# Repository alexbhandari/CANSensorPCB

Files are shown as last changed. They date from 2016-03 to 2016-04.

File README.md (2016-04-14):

# Sensor to CAN Bus Remote IO PCB
Many wires in, two wires out. 24 input channels on the board interface with analog and digital sensors. Performs analog to digital to CAN protocol conversion.

## Changelog
| Release | Changes |
| --- | --- |
|  | Pre-release |

## PCB Design

- Microcontroller: RM42L432BPZT
- Input Stage: Filtering, Voltage scaling, Circuit Protection
- Output Stage: 2 Isolated CAN transceivers
- Power: 5V board power, LDO supply creates 3.3V and 1.2V

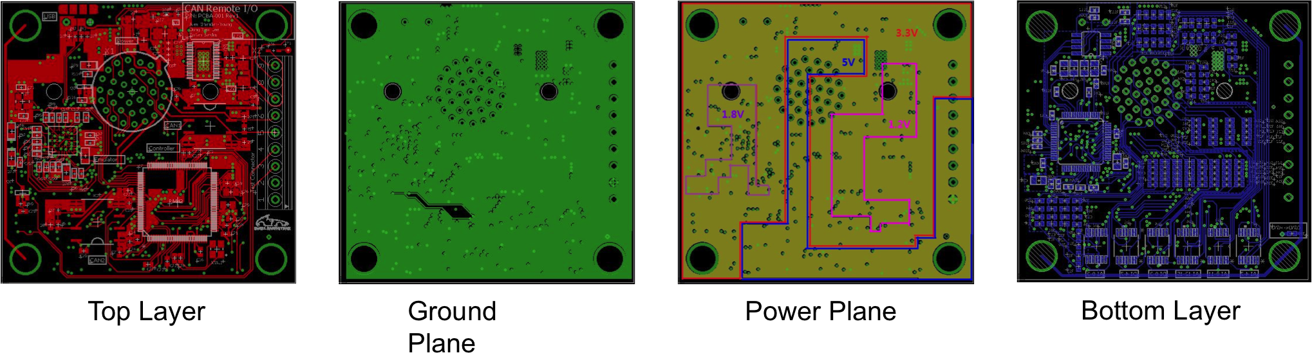
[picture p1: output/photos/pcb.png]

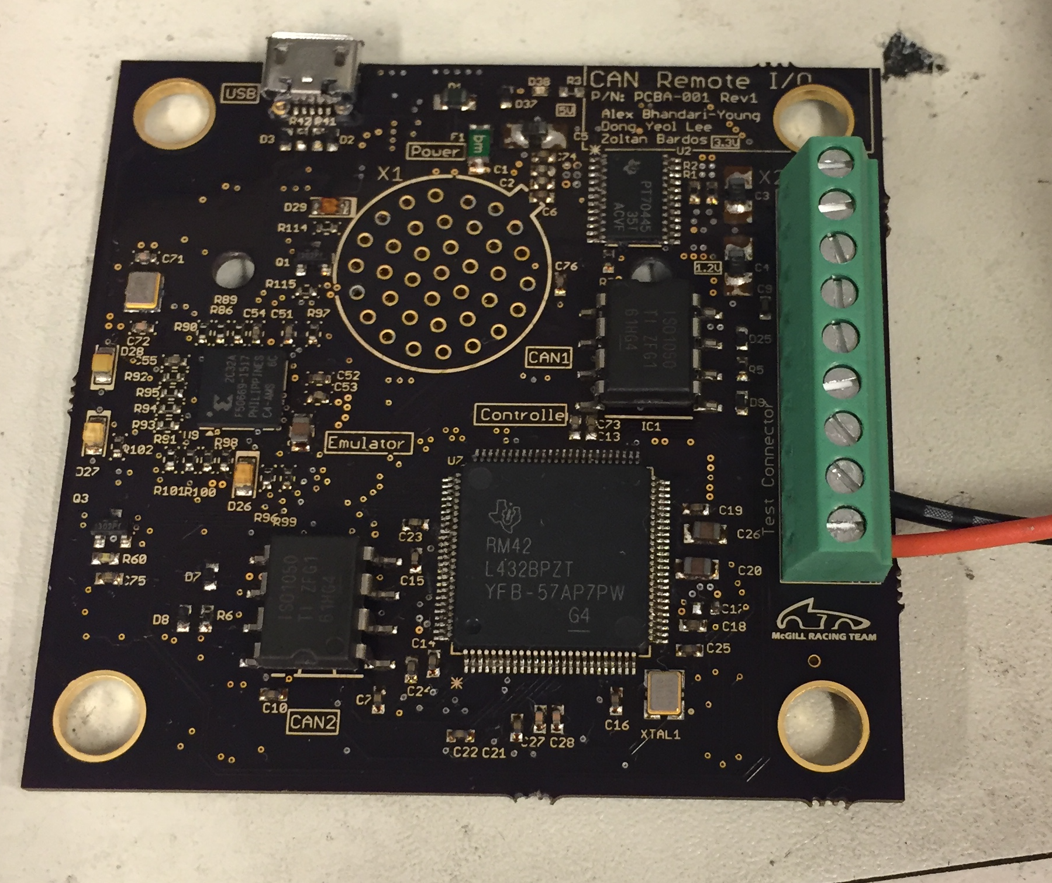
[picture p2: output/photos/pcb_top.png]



## [Code Repo](https://github.com/alexbhandari/RM42-CAN-Sensor-Code)

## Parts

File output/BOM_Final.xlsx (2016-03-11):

Item # | Ref Des | Qty | Manufacturer | Mfg Part # | Description | Package | Type | Your Instructions | Value | Device
 | C8, C32, C33, C34, C35, C43, C44, C45 | 8 | Murata Electronics North America | GRM155R71H103KA88D | CAP CER 10000PF 50V X7R 0402 | 0402 | SMD |  | .01uF | CAP0402
 | C7, C9, C10, C76 | 4 | Murata Electronics North America | GRM155R71C104JA88D | CAP CER 0.1UF 16V X7R 0402 | 0402 | SMD |  | .1uF | CAP0402
 | R86, R89, R90, R91, R92, R93, R94, R95, R103, R104, R105 | 11 | Yageo | RC0402JR-070RL | RES SMD 0.0OHM JUMPER 1/16W 0402 | 0402 | SMD |  | 0R | RES0402
 | F1 | 1 | Bel Fuse Inc. | 0ZCJ0050AF2E | PTC RESTTBLE 0.50A 24V CHIP 1206 | 1206 | SMD |  | 0ZCJ0050AF2E | PTCFUSE-1206
 | R7, R115 | 2 | Yageo | RC0402FR-07100KL | RES SMD 100K OHM 1% 1/16W 0402 | 0402 | SMD |  | 100K | RES0402
 | C13, C14, C15, C16, C17, C18, C19, C21, C22, C23, C24, C25, C73, C75, C51, C52, C53, C54, C55, C60, C61, C62, C63, C64, C65, C66, C67, C68, C69, C70, C6, C74 | 32 | Murata Electronics North America | GRM155R71C104JA88D | CAP CER 0.1UF 16V X7R 0402 | 0402 | SMD |  | 100nF | CAP0402
 | R97, R102 | 2 | Yageo | RC0402JR-0710KL | RES SMD 10K OHM 5% 1/16W 0402 | 0402 | SMD |  | 10K | RES0402
 | R5,R6,R114 | 3 | Vishay Dale | CRCW0402120RJNEDHP | RES SMD 120 OHM 5% 1/5W 0402 | 0402 | SMD |  | 120R | RES0402
 | R110 | 1 | Yageo | RC0402JR-0712KL | RES SMD 12K OHM 5% 1/16W 0402 | 0402 | SMD |  | 12K | RES0402
 | Y1 | 1 | TXC | 7M-12.000MEEQ-T | Crystal 12MHZ | 3.2*2.5mm | SMD |  | 12M | CRYSTAL-SMD
 | X2 | 1 | Phoenix Contact | 1751316 | CONN TERM BLOCK 9POS 3.5MM | 32*7.3mm | Through Hole |  | 1751316 | 1751316
 | R40, R66, R67, R68, R69, R77, R78, R79, R98, R99, R100, R101 | 12 | Yageo | RC0402FR-071KL | RES SMD 1K OHM 1% 1/16W 0402 | 0402 | SMD |  | 1K | RES0402
 | C1, C2,C11, C12, C29, C30, C31, C36, C37, C38, C39, C40, C41, C42, C47, C48, C49, C50 | 18 | Murata Electronics North America | GRM155R60J105KE19D | CAP CER 1UF 6.3V X5R 0402 | 0402 | SMD |  | 1uF | CAP0402
 | R108 | 1 | Panasonic Electronic Components | ERJ-2GEJ222X | RES SMD 2.2K OHM 5% 1/10W 0402 | 0402 | SMD |  | 2.2K | RES0402
 | R8,R10, R12, R14, R16, R18, R20, R22, R24, R26, R28, R30, R32, R34, R36, R38, R43, R45, R47, R49, R51, R53, R55, R57 | 24 | Susumu | RR0510P-203-D | RES SMD 20K OHM 0.5% 1/16W 0402 | 0402 | SMD |  | 20K | RES0402
 | R96,R106, R107 | 3 | Panasonic Electronic Components | ERJ-2RKF2000X | RES SMD 200 OHM 1% 1/10W 0402 | 0402 | SMD |  | 200 | RES0402
 | R41, R42 | 2 | Yageo | RC0402FR-0722RL | RES SMD 22 OHM 1% 1/16W 0402 | 0402 | SMD |  | 22 | RES0402
 | FB1, FB2 | 2 | MURATA | BLM21PG221SN1D | Ferrite Bead | 0805 | SMD |  | 220R @ 100M | INDUCTOR
 | C27, C28, C71, C72 | 4 | Johanson Technology Inc. | 500R07S220JV4T | CAP CER 22PF 50V NP0 0402 | 0402 | SMD |  | 22pF | CAP0402
 | C3, C5 | 2 | AVX Corporation | F920J226MPA | CAP TANT 22UF 6.3V 20% 0805 | 0805 | SMD |  | 22uF | CAP0805
 | R3 | 1 | Samsung Electro-Mechanics America, Inc. | RC1005F6190CS | RES SMD 619 OHM 1% 1/16W 0402 | 0402 | SMD |  | 619 | RES0402
 | R1, R2 | 2 | Yageo | RC0402FR-07249KL | RES SMD 249K OHM 1% 1/16W 0402 | 0402 | SMD |  | 250k | RES0402
 | R9, R11, R13, R15, R17, R19, R21, R23, R25, R27, R29, R31, R33, R35, R37, R39, R44, R46, R48, R50, R52, R54, R56, R58, R60 | 25 | Susumu | RR0510P-393-D | RES SMD 39K OHM 0.5% 1/16W 0402 | 0402 | SMD |  | 39K | RES0402
 | R109, R111, R112, R113 | 4 | Yageo | RC0402JR-074K7L | RES SMD 4.7K OHM 5% 1/16W 0402 | 0402 | SMD |  | 4.7K | RES0402
 | C20, C26, C46, C56, C57, C58, C59 | 7 | Taiyo Yuden | LMK212BJ475KD-T | CAP CER 4.7UF 10V X5R 0805 | 0805 | SMD |  | 4.7uF | CAP0805
 | C4 | 1 | Murata Electronics North America | GRM155R71E473KA88D | CAP CER 0.047UF 25V X7R 0402 | 0402 | SMD |  | 47uF | CAP0402
 | R61, R62, R63, R64, R65, R70, R71, R72, R73, R74, R75, R76, R81, R82, R83, R84 | 16 | Panasonic Electronic Components | ERJ-2RKF6980X | RES SMD 698 OHM 1% 1/10W 0402 | 0402 | SMD |  | 698 | RES0402
 | XTAL1 | 1 | TXC | 7M-16.000MAAJ-T | Crystal 16MHZ | 3.2*2.5mm | SMD |  | 7M-16.000MAAJ-T | CRYSTAL-SMD
 | U11 | 1 | Microchip Technology | 93LC56C-I/SN | IC EEPROM 2KBIT 3MHZ 8SOIC | 8-SOIC | SMD |  | 93LC56C-I/SN | 93LC56C-I/SN
 | X1 | 1 | Deutch | AS214-35-PN | Autosport connector |  |  | do not populate | AS14-35 | AS14-35
 | R59 | 1 |  |  |  |  |  |  | DNP | RES0402
 | Q1, Q3 | 2 | Fairchild Semiconductor | FDV302P | MOSFET P-CH 25V 120MA SOT-23 | SOT-23 | SMD |  | FDV302P | PMOSSOT23
 | U10 | 1 | FTDI, Future Technology Devices International Ltd | FT2232HL | IC USB HS DUAL UART/FIFO 64-LQFP | 64-LQFP | SMD |  | FT2232HL | FT2232HL
 | IC1, IC2 | 2 | Texas Instruments | ISO1050DUBR | IC TXRX CAN 5V 8SOP | 8-SOP | SMD |  | ISO1050DUB | ISO1050DUB
 | U1, U3, U4, U5, U6, U8 | 6 | Texas Instruments | LM324PW | IC OPAMP GP 1.2MHZ 14TSSOP | 14-TSSOP | SMD |  | LM324PW | LM324PW
 | U7 | 1 | Texas Instruments | RM42L432BPZT | IC MCU 16BIT 384KB FLASH 100LQFP | 100-LQFP | SMD |  | RM42L432_PZ_100RM42L432_PZ_100 | RM42L432_PZ_100RM42L432_PZ_100
 | U2 | 1 | Texas Instruments | TPS70445PWP | IC REG LDO 3.3V/1.2V 24HTSSOP | 24-HTSSOP | SMD |  | TPS70445_PWP_24 | TPS70445_PWP_24
 | D2, D3, D4, D5, D6, D7, D8, D9, D10, D11, D12, D13, D14, D15, D16, D17, D18, D19, D20, D21, D22, D23, D24, D25, D30, D31, D32, D33, D34, D35 | 30 | Semtech Corporation | UCLAMP1201P.TCT | TVS DIODE 12VWM 25VC 2SLP | 0402 | SMD |  | TVS DIODE | TVS0402
 | U$5 | 1 | Molex, LLC | 1050170001 | USB - micro B Receptacle Connector 5 Position Board Cutout, Surface Mount, Right Angle | 7.5*5.0mm | SMD |  | USB-CON-5PIN-105017-0001 | USB-CON-5PIN-105017-0001
 | U9 | 1 | Xilinx Inc. | XC2C32A-6CP56C | IC CPLD 32MC 5.5NS 56BGA | 56-LFBGA, CSPBGA | SMD |  | XC2C32A-6CP56C | XC2C32A-6CP56C | possibe replacment: XC2C64A-7CPG56I
 | D26, D27 | 1 | Lite-On Inc. | LTST-C170TBKT | LED BLUE CLEAR 0805 SMD | 0805 | SMD |  | BLUE | CHIP-LED-BLUE
 | D28 | 1 | Lite-On Inc. | LTW-170TK | LED WHITE 0805 SMD | 0805 | SMD |  | YELLOW | CHIP-LED-YELLOW
 | D29 | 1 | Kingbright | APHCM2012ZGC-F01 | LED GREEN CLEAR 0805 SMD | 0805 | SMD |  | GREEN | CHIP-LED-GREEN
 | D36 | 1 | ON Semiconductor | NSR0320MW2T1G | DIODE SCHOTTKY 20V 1A SOD323 | SOD323 | SMD |  | 20V | DSOD323
 | D38 | 1 | Kingbright | APG1005VGC-T-5MAV | LED GREEN CLEAR 0402 SMD | 0402 | SMD |  | GREEN | CHIP-LED-GREEN
 | D37 | 1 | Comchip Technology | CPDQR5V0USP-HF | DIODE ESD 5V UNIDIR 0402 |  | SMD |  | 5V | Zener
 | D1 | 1 | Littelfuse Inc. | V5.5MLA0805NH | VARISTOR 7.1V 120A 0805 |  | SMD |  | 5.5V | Varistor

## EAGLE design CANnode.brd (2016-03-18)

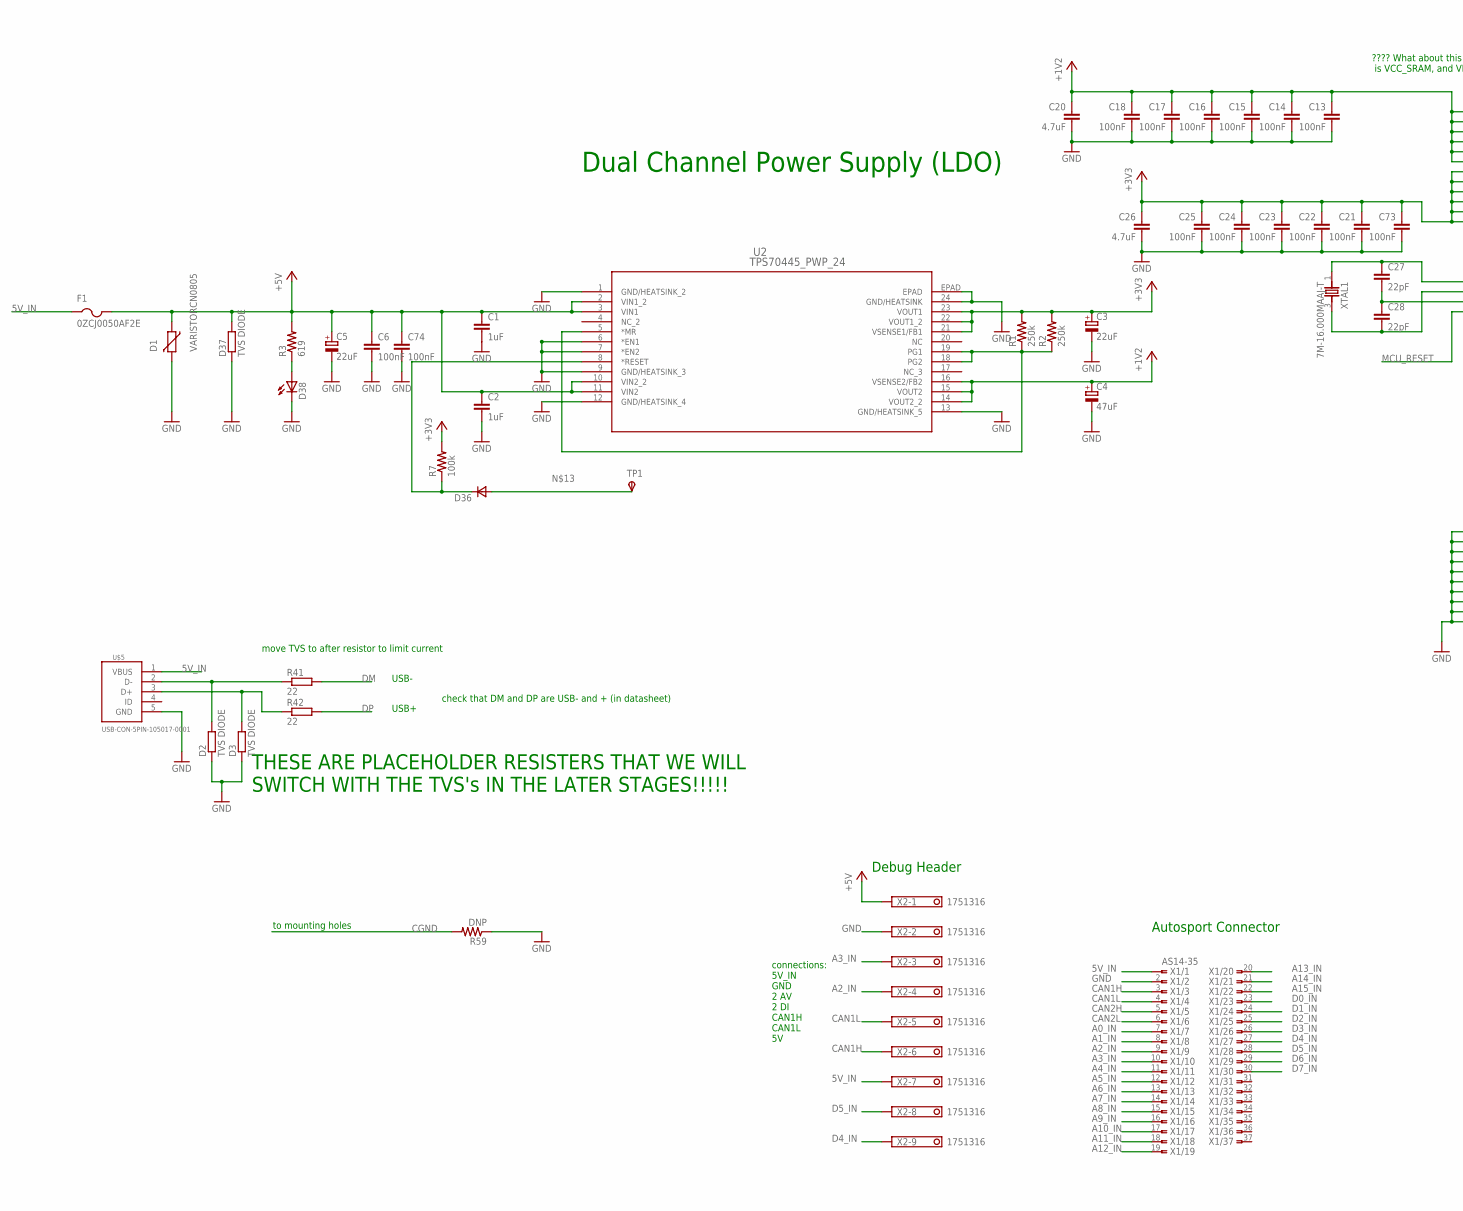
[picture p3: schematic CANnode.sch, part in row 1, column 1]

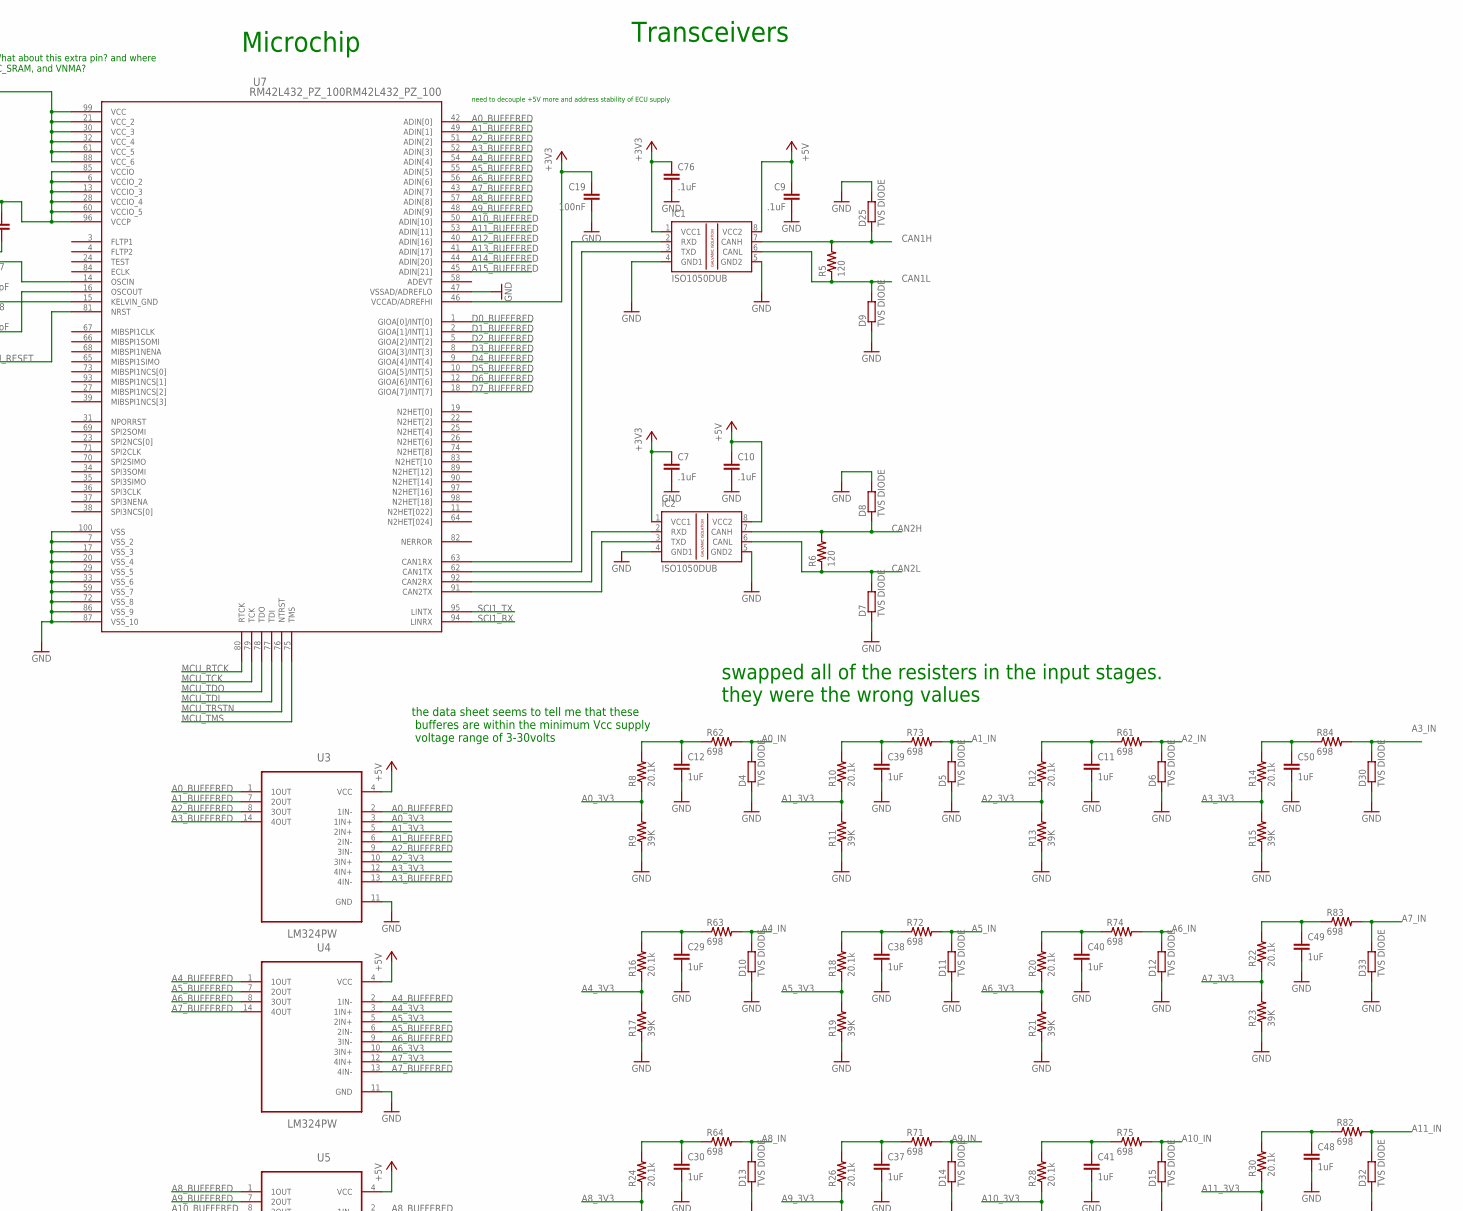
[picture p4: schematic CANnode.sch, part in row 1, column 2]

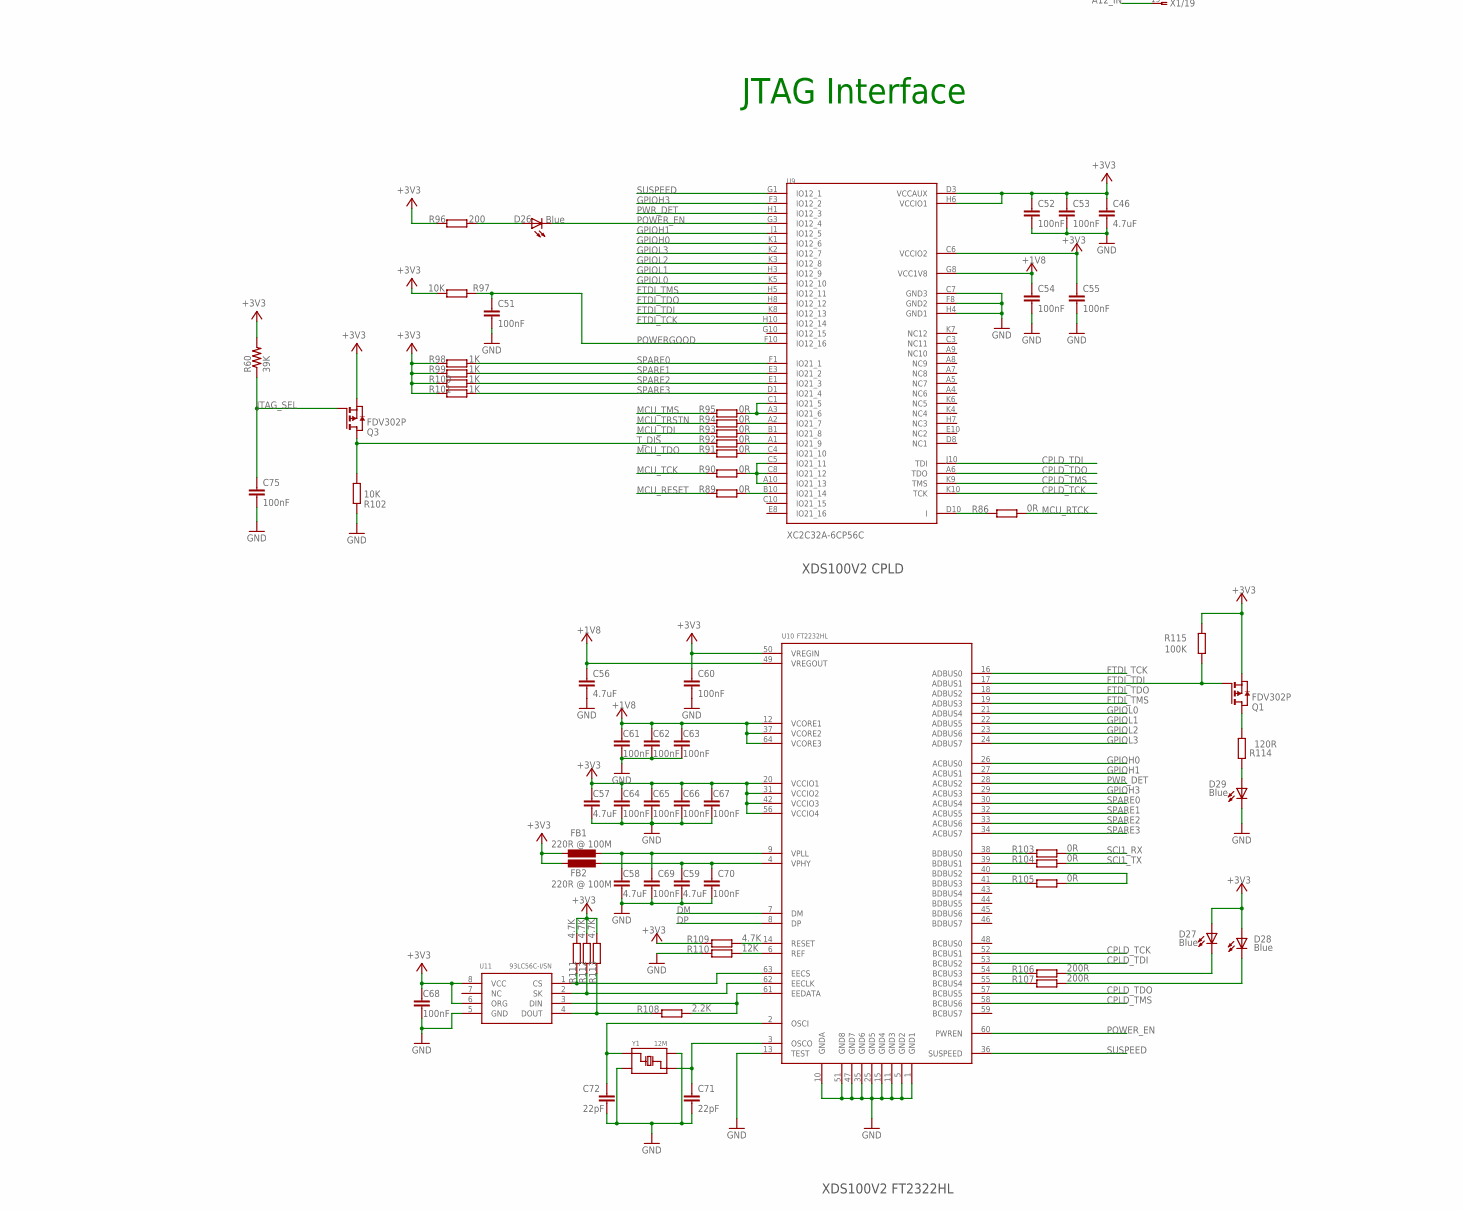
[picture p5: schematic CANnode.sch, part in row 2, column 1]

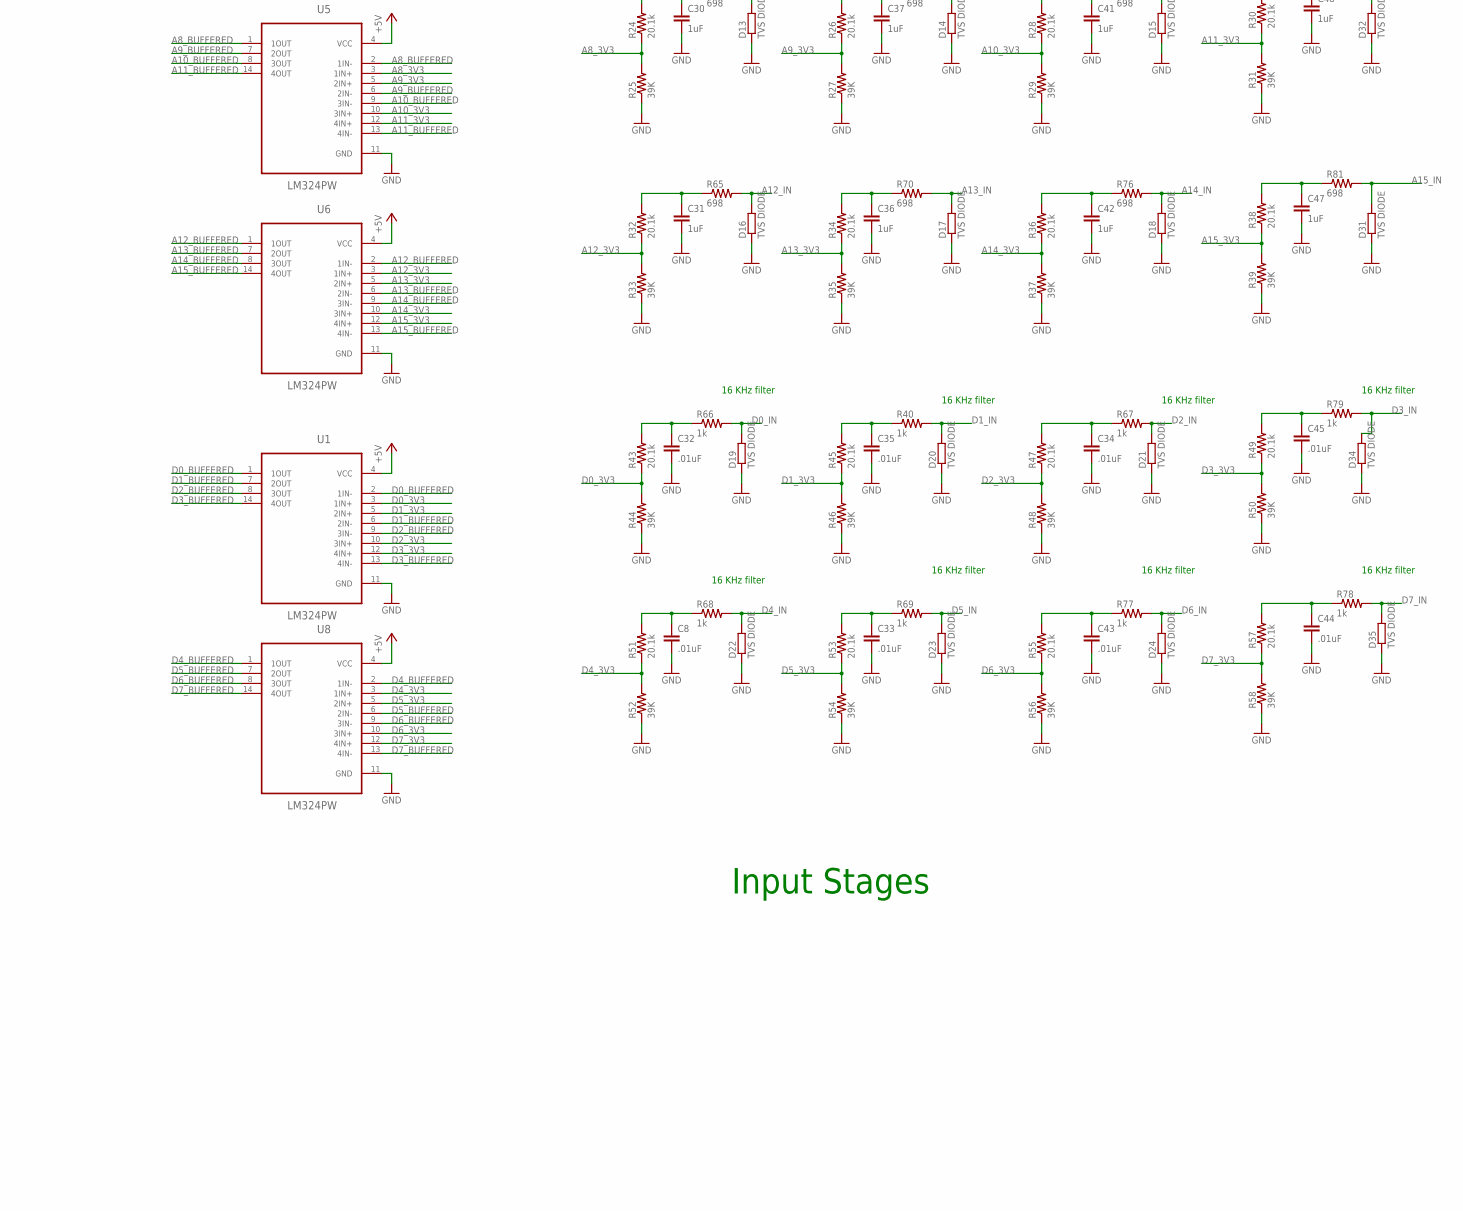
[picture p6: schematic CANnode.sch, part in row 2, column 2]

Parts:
C1, C2, C11, C12, C29, C30, C31, C36, C37, C38, C39, C40, C41, C42, C47, C48, C49, C50: 1uF; C0402
C3, C5: 22uF; CT3528
C4: 47uF; CT3528
C6, C13, C14, C15, C16, C17, C18, C19, C21, C22, C23, C24, C25, C73, C74, C75: 100nF; C0402
C7, C9, C10, C76: .1uF; C0402
C8, C32, C33, C34, C35, C43, C44, C45: .01uF; C0402
C20, C26: 4.7uF; C0805
C27, C28: 22pF; C0402
C46, C56, C57, C58, C59: 4.7uF; 0805
C51, C52, C53, C54, C55, C60, C61, C62, C63, C64, C65, C66, C67, C68, C69, C70: 100nF; 0402
C71, C72: 22pF; 0402
D1: VARISTORCN0805; CT/CN0805
D2, D3, D4, D5, D6, D7, D8, D9, D10, D11, D12, D13, D14, D15, D16, D17, D18, D19, D20, D21, D22, D23, D24, D25, D30, D31, D32, D33, D34, D35, D37: TVS DIODE; R0402
D26, D27, D28, D29: Blue; LED0805
D36: DSOD323; SOD323
D38: LED; SMARTLED-TTW
F1: 0ZCJ0050AF2E; R1206
FB1, FB2: 220R @ 100M; 0805
IC1, IC2: ISO1050DUB; DUB-R-PDSO-G8
Q1, Q3: FDV302P; SOT-23
R1, R2: 250k; R0402
R3: 619; R0402
R5, R6: 120; R0402
R7: 100k; R0402
R8: 20.1K; R0402
R9, R11, R13, R15, R17, R19, R21, R23, R25, R27, R29, R31, R33, R35, R37, R39, R44, R46, R48, R50, R52, R54, R56, R58, R60: 39K; R0402
R10, R12, R14, R16, R18, R20, R22, R24, R26, R28, R30, R32, R34, R36, R38, R43, R45, R47, R49, R51, R53, R55, R57: 20.1k; R0402
R40, R66, R67, R68, R69, R77, R78, R79: 1k; R0402
R41, R42: 22; R0402
R59: DNP; R0402
R61, R62, R63, R64, R65, R70, R71, R72, R73, R74, R75, R76, R81, R82, R83, R84: 698; R0402
R86, R89, R90, R91, R92, R93, R94, R95, R103, R104, R105: 0R; 0402
R96: 200; 0402
R97, R102: 10K; 0402
R98, R99, R100, R101: 1K; 0402
R106, R107: 200R; 0402
R108: 2.2K; 0402
R109, R111, R112, R113: 4.7K; 0402
R110: 12K; 0402
R114: 120R; 0402
R115: 100K; 0402
TP1: TPSB1,27; B1,27
U1, U3, U4, U5, U6, U8: LM324PW; SOP65P640X120-14N
U2: TPS70445_PWP_24; PWP24_4P68X2P4
U7: RM42L432_PZ_100RM42L432_PZ_100; PZ100
U9: XC2C32A-6CP56C; CP56
U10: FT2232HL; LQFP64
U11: 93LC56C-I/SN; SO8
U$5: USB-CON-5PIN-105017-0001; USB-MICRO-MOLEX-105017-0001
X1: AS14-35
X2: 1751316
XTAL1: 7M-16.000MAAJ-T; TXC_7M-16.000MAAJ-T
Y1: 12M; CRYSTAL_3225

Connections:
5V_IN: F1.1, U$5.1 (VBUS), X1.1, X2.7
+1V2: C4.- (+), C13.1, C14.1, C15.1, C16.1, C17.1, C18.1, C20.1, U2.14 (VOUT2_2), U2.15 (VOUT2), U2.16 (VSENSE2/FB2), U7.21 (VCC_2), U7.30 (VCC_3), U7.32 (VCC_4), U7.61 (VCC_5), U7.88 (VCC_6), U7.99 (VCC)
+1V8: C54.1, C56.1, C61.1, C62.1, C63.1, U9.G8 (VCC1V8), U10.12 (VCORE1), U10.37 (VCORE2), U10.49 (VREGOUT), U10.64 (VCORE3)
+3V3: C3.- (+), C7.1, C19.1, C21.1, C22.1, C23.1, C24.1, C25.1, C26.1, C46.1, C52.1, C53.1, C55.1, C57.1, C60.1, C64.1, C65.1, C66.1, C67.1, C68.1, C73.1, C76.1, D27.A, D28.A, FB1.1, FB2.1, IC1.1 (VCC1), IC2.1 (VCC1), Q1.2 (S), Q3.2 (S), R1.2, R2.2, R7.2, R60.2, R96.1, R97.2, R98.1, R99.1, R100.1, R101.1, R109.1, R111.2, R112.2, R113.2, R115.2, U2.21 (VSENSE1/FB1), U2.22 (VOUT1_2), U2.23 (VOUT1), U7.6 (VCCIO_2), U7.13 (VCCIO_3), U7.28 (VCCIO_4), U7.46 (VCCAD/ADREFHI), U7.60 (VCCIO_5), U7.85 (VCCIO), U7.96 (VCCP), U9.C6 (VCCIO2), U9.D3 (VCCAUX), U9.H6 (VCCIO1), U10.20 (VCCIO1), U10.31 (VCCIO2), U10.42 (VCCIO3), U10.50 (VREGIN), U10.56 (VCCIO4), U11.6 (ORG), U11.8 (VCC)
+5V: C1.1, C2.1, C5.- (+), C6.1, C9.1, C10.1, C74.1, D1.1, D37.2, F1.2, IC1.8 (VCC2), IC2.8 (VCC2), R3.2, U1.4 (VCC), U2.2 (VIN1_2), U2.3 (VIN1), U2.10 (VIN2_2), U2.11 (VIN2), U3.4 (VCC), U4.4 (VCC), U5.4 (VCC), U6.4 (VCC), U8.4 (VCC), X2.1
A0_3V3: R8.1, R9.2, U3.3 (1IN+)
A0_BUFFERED: U3.1 (1OUT), U3.2 (1IN-), U7.42 (ADIN[0])
A0_IN: D4.2, R62.2, X1.7
A1_3V3: R10.1, R11.2, U3.5 (2IN+)
A1_BUFFERED: U3.6 (2IN-), U3.7 (2OUT), U7.49 (ADIN[1])
A1_IN: D5.2, R73.2, X1.8
A2_3V3: R12.1, R13.2, U3.10 (3IN+)
A2_BUFFERED: U3.8 (3OUT), U3.9 (3IN-), U7.51 (ADIN[2])
A2_IN: D6.2, R61.2, X1.9, X2.4
A3_3V3: R14.1, R15.2, U3.12 (4IN+)
A3_BUFFERED: U3.13 (4IN-), U3.14 (4OUT), U7.52 (ADIN[3])
A3_IN: D30.2, R84.2, X1.10, X2.3
A4_3V3: R16.1, R17.2, U4.3 (1IN+)
A4_BUFFERED: U4.1 (1OUT), U4.2 (1IN-), U7.54 (ADIN[4])
A4_IN: D10.2, R63.2, X1.11
A5_3V3: R18.1, R19.2, U4.5 (2IN+)
A5_BUFFERED: U4.6 (2IN-), U4.7 (2OUT), U7.55 (ADIN[5])
A5_IN: D11.2, R72.2, X1.12
A6_3V3: R20.1, R21.2, U4.10 (3IN+)
A6_BUFFERED: U4.8 (3OUT), U4.9 (3IN-), U7.56 (ADIN[6])
A6_IN: D12.2, R74.2, X1.13
A7_3V3: R22.1, R23.2, U4.12 (4IN+)
A7_BUFFERED: U4.13 (4IN-), U4.14 (4OUT), U7.43 (ADIN[7])
A7_IN: D33.2, R83.2, X1.14
A8_3V3: R24.1, R25.2, U5.3 (1IN+)
A8_BUFFERED: U5.1 (1OUT), U5.2 (1IN-), U7.57 (ADIN[8])
A8_IN: D13.2, R64.2, X1.15
A9_3V3: R26.1, R27.2, U5.5 (2IN+)
A9_BUFFERED: U5.6 (2IN-), U5.7 (2OUT), U7.48 (ADIN[9])
A9_IN: D14.2, R71.2, X1.16
A10_3V3: R28.1, R29.2, U5.10 (3IN+)
A10_BUFFERED: U5.8 (3OUT), U5.9 (3IN-), U7.50 (ADIN[10])
A10_IN: D15.2, R75.2, X1.17
A11_3V3: R30.1, R31.2, U5.12 (4IN+)
A11_BUFFERED: U5.13 (4IN-), U5.14 (4OUT), U7.53 (ADIN[11])
A11_IN: D32.2, R82.2, X1.18
A12_3V3: R32.1, R33.2, U6.3 (1IN+)
A12_BUFFERED: U6.1 (1OUT), U6.2 (1IN-), U7.40 (ADIN[16])
A12_IN: D16.2, R65.2, X1.19
A13_3V3: R34.1, R35.2, U6.5 (2IN+)
A13_BUFFERED: U6.6 (2IN-), U6.7 (2OUT), U7.41 (ADIN[17])
A13_IN: D17.2, R70.2, X1.20
A14_3V3: R36.1, R37.2, U6.10 (3IN+)
A14_BUFFERED: U6.8 (3OUT), U6.9 (3IN-), U7.44 (ADIN[20])
A14_IN: D18.2, R76.2, X1.21
A15_3V3: R38.1, R39.2, U6.12 (4IN+)
A15_BUFFERED: U6.13 (4IN-), U6.14 (4OUT), U7.45 (ADIN[21])
A15_IN: D31.2, R81.2, X1.22
CAN1H: D25.1, IC1.7 (CANH), R5.2, X1.3, X2.6
CAN1L: D9.2, IC1.6 (CANL), R5.1, X1.4, X2.5
CAN1RX: IC1.2 (RXD), U7.63 (CAN1RX)
CAN1TX: IC1.3 (TXD), U7.62 (CAN1TX)
CAN2H: D8.1, IC2.7 (CANH), R6.2, X1.5
CAN2L: D7.2, IC2.6 (CANL), R6.1, X1.6
CAN2RX: IC2.2 (RXD), U7.92 (CAN2RX)
CAN2TX: IC2.3 (TXD), U7.91 (CAN2TX)
CGND: R59.2
CPLD_TCK: U9.K10 (TCK), U10.52 (BCBUS1)
CPLD_TDI: U9.J10 (TDI), U10.53 (BCBUS2)
CPLD_TDO: U9.A6 (TDO), U10.57 (BCBUS5)
CPLD_TMS: U9.K9 (TMS), U10.58 (BCBUS6)
D0_3V3: R43.1, R44.2, U1.3 (1IN+)
D0_BUFFERED: U1.1 (1OUT), U1.2 (1IN-), U7.1 (GIOA[0]/INT[0])
D0_IN: D19.2, R66.2, X1.23
D1_3V3: R45.1, R46.2, U1.5 (2IN+)
D1_BUFFERED: U1.6 (2IN-), U1.7 (2OUT), U7.2 (GIOA[1]/INT[1])
D1_IN: D20.2, R40.2, X1.24
D2_3V3: R47.1, R48.2, U1.10 (3IN+)
D2_BUFFERED: U1.8 (3OUT), U1.9 (3IN-), U7.5 (GIOA[2]/INT[2])
D2_IN: D21.2, R67.2, X1.25
D3_3V3: R49.1, R50.2, U1.12 (4IN+)
D3_BUFFERED: U1.13 (4IN-), U1.14 (4OUT), U7.8 (GIOA[3]/INT[3])
D3_IN: D34.2, R79.2, X1.26
D4_3V3: R51.1, R52.2, U8.3 (1IN+)
D4_BUFFERED: U7.9 (GIOA[4]/INT[4]), U8.1 (1OUT), U8.2 (1IN-)
D4_IN: D22.2, R68.2, X1.27, X2.9
D5_3V3: R53.1, R54.2, U8.5 (2IN+)
D5_BUFFERED: U7.10 (GIOA[5]/INT[5]), U8.6 (2IN-), U8.7 (2OUT)
D5_IN: D23.2, R69.2, X1.28, X2.8
D6_3V3: R55.1, R56.2, U8.10 (3IN+)
D6_BUFFERED: U7.12 (GIOA[6]/INT[6]), U8.8 (3OUT), U8.9 (3IN-)
D6_IN: D24.2, R77.2, X1.29
D7_3V3: R57.1, R58.2, U8.12 (4IN+)
D7_BUFFERED: U7.18 (GIOA[7]/INT[7]), U8.13 (4IN-), U8.14 (4OUT)
D7_IN: D35.2, R78.2, X1.30
DM: R41.2, U10.7 (DM)
DP: R42.2, U10.8 (DP)
FTDI_TCK: U9.H10 (IO12_14), U10.16 (ADBUS0)
FTDI_TDI: Q1.3 (G), R115.1, U9.K8 (IO12_13), U10.17 (ADBUS1)
FTDI_TDO: U9.H8 (IO12_12), U10.18 (ADBUS2)
FTDI_TMS: U9.H5 (IO12_11), U10.19 (ADBUS3)
GND: C1.2, C2.2, C3.+ (-), C4.+ (-), C5.+ (-), C6.2, C7.2, C8.2, C9.2, C10.2, C11.2, C12.2, C13.2, C14.2, C15.2, C16.2, C17.2, C18.2, C19.2, C20.2, C21.2, C22.2, C23.2, C24.2, C25.2, C26.2, C29.2, C30.2, C31.2, C32.2, C33.2, C34.2, C35.2, C36.2, C37.2, C38.2, C39.2, C40.2, C41.2, C42.2, C43.2, C44.2, C45.2, C46.2, C47.2, C48.2, C49.2, C50.2, C51.2, C52.2, C53.2, C54.2, C55.2, C56.2, C57.2, C58.2, C59.2, C60.2, C61.2, C62.2, C63.2, C64.2, C65.2, C66.2, C67.2, C68.2, C69.2, C70.2, C71.2, C72.2, C73.2, C74.2, C75.2, C76.2, D1.2, D2.1, D3.1, D4.1, D5.1, D6.1, D7.1, D8.2, D9.1, D10.1, D11.1, D12.1, D13.1, D14.1, D15.1, D16.1, D17.1, D18.1, D19.1, D20.1, D21.1, D22.1, D23.1, D24.1, D25.2, D29.C, D30.1, D31.1, D32.1, D33.1, D34.1, D35.1, D37.1, D38.C@1 (C), IC1.4 (GND1), IC1.5 (GND2), IC2.4 (GND1), IC2.5 (GND2), R9.1, R11.1, R13.1, R15.1, R17.1, R19.1, R21.1, R23.1, R25.1, R27.1, R29.1, R31.1, R33.1, R35.1, R37.1, R39.1, R44.1, R46.1, R48.1, R50.1, R52.1, R54.1, R56.1, R58.1, R59.1, R102.1, R110.1, U1.11 (GND), U2.1 (GND/HEATSINK_2), U2.6 (*EN1), U2.7 (*EN2), U2.9 (GND/HEATSINK_3), U2.12 (GND/HEATSINK_4), U2.13 (GND/HEATSINK_5), U2.24 (GND/HEATSINK), U2.EPAD, U3.11 (GND), U4.11 (GND), U5.11 (GND), U6.11 (GND), U7.7 (VSS_2), U7.17 (VSS_3), U7.20 (VSS_4), U7.29 (VSS_5), U7.33 (VSS_6), U7.47 (VSSAD/ADREFLO), U7.59 (VSS_7), U7.72 (VSS_8), U7.86 (VSS_9), U7.87 (VSS_10), U7.100 (VSS), U8.11 (GND), U9.C7 (GND3), U9.F8 (GND2), U9.H4 (GND1), U10.1 (GND1), U10.5 (GND2), U10.10 (GNDA), U10.11 (GND3), U10.13 (TEST), U10.15 (GND4), U10.25 (GND5), U10.35 (GND6), U10.47 (GND7), U10.51 (GND8), U11.5 (GND), U$5.5 (GND), X1.2, X2.2, Y1.P$2, Y1.P$4
GPIOH0: U9.K1 (IO12_6), U10.26 (ACBUS0)
GPIOH1: U9.J1 (IO12_5), U10.27 (ACBUS1)
GPIOH3: U9.F3 (IO12_2), U10.29 (ACBUS3)
GPIOL0: U9.K5 (IO12_10), U10.21 (ADBUS4)
GPIOL1: U9.H3 (IO12_9), U10.22 (ADBUS5)
GPIOL2: U9.K3 (IO12_8), U10.23 (ADBUS6)
GPIOL3: U9.K2 (IO12_7), U10.24 (ADBUS7)
JTAG_SEL: C75.1, Q3.3 (G), R60.1
MCU_RESET: R89.1, U7.81 (NRST)
MCU_RTCK: R86.2, U7.80 (RTCK)
MCU_TCK: R90.1, U7.79 (TCK)
MCU_TDI: R93.1, U7.77 (TDI)
MCU_TDO: R91.1, U7.78 (TDO)
MCU_TMS: R95.1, U7.75 (TMS)
MCU_TRSTN: R94.1, U7.76 (NTRST)
unnamed: R1.1, R2.1, U2.5 (*MR), U2.18 (PG2), U2.19 (PG1)
unnamed: D38.A@1 (A), R3.1
unnamed: C58.1, C69.1, FB1.2, U10.9 (VPLL)
unnamed: C59.1, C70.1, FB2.2, U10.4 (VPHY)
unnamed: R110.2, U10.6 (REF)
unnamed: R109.2, U10.14 (RESET)
unnamed: C72.1, U10.2 (OSCI), Y1.P$3
unnamed: D36.1 (C), R7.1, U2.8 (*RESET)
unnamed: D36.2 (A), TP1.TP
unnamed: C27.2, C28.1, U7.15 (KELVIN_GND)
unnamed: C27.1, U7.14 (OSCIN), XTAL1.1
unnamed: C71.1, U10.3 (OSCO), Y1.P$1
unnamed: C28.2, U7.16 (OSCOUT), XTAL1.3
unnamed: R111.1, U10.63 (EECS), U11.1 (CS)
unnamed: R112.1, U10.62 (EECLK), U11.2 (SK)
unnamed: D2.2, R41.1, U$5.2 (D-)
unnamed: D3.2, R42.1, U$5.3 (D+)
unnamed: D26.A, R96.2
unnamed: R108.2, U10.61 (EEDATA), U11.3 (DIN)
unnamed: R108.1, R113.1, U11.4 (DOUT)
unnamed: R106.1, U10.54 (BCBUS3)
unnamed: R107.1, U10.55 (BCBUS4)
unnamed: R103.1, U10.38 (BDBUS0)
unnamed: R104.1, U10.39 (BDBUS1)
unnamed: R95.2, U9.A3 (IO21_6), U9.C1 (IO21_5)
unnamed: Q1.1 (D), R114.2
unnamed: R94.2, U9.A2 (IO21_7)
unnamed: R93.2, U9.B1 (IO21_8)
unnamed: R92.2, U9.A1 (IO21_9)
unnamed: R91.2, U9.C4 (IO21_10)
unnamed: R90.2, U9.A10 (IO21_13), U9.C5 (IO21_11), U9.C8 (IO21_12)
unnamed: R89.2, U9.B10 (IO21_14)
unnamed: D29.A, R114.1
unnamed: R105.2, U10.40 (BDBUS2)
unnamed: R105.1, U10.41 (BDBUS3)
unnamed: R86.1, U9.D10 (I)
unnamed: D27.C, R106.2
unnamed: D28.C, R107.2
unnamed: C11.1, R12.2, R61.1
unnamed: C12.1, R8.2, R62.1
unnamed: C29.1, R16.2, R63.1
unnamed: C30.1, R24.2, R64.1
unnamed: C31.1, R32.2, R65.1
unnamed: C32.1, R43.2, R66.1
unnamed: C8.1, R51.2, R68.1
unnamed: C33.1, R53.2, R69.1
unnamed: C35.1, R40.1, R45.2
unnamed: C36.1, R34.2, R70.1
unnamed: C37.1, R26.2, R71.1
unnamed: C38.1, R18.2, R72.1
unnamed: C39.1, R10.2, R73.1
unnamed: C40.1, R20.2, R74.1
unnamed: C41.1, R28.2, R75.1
unnamed: C42.1, R36.2, R76.1
unnamed: C34.1, R47.2, R67.1
unnamed: C43.1, R55.2, R77.1
unnamed: C44.1, R57.2, R78.1
unnamed: C45.1, R49.2, R79.1
unnamed: C47.1, R38.2, R81.1
unnamed: C48.1, R30.2, R82.1
unnamed: C49.1, R22.2, R83.1
unnamed: C50.1, R14.2, R84.1
POWERGOOD: C51.1, R97.1, U9.F10 (IO12_16)
POWER_EN: D26.C, U9.G3 (IO12_4), U10.60 (PWREN)
PWR_DET: U9.H1 (IO12_3), U10.28 (ACBUS2)
SCI1_RX: R103.2, U7.94 (LINRX)
SCI1_TX: R104.2, U7.95 (LINTX)
SPARE0: R98.2, U9.F1 (IO21_1), U10.30 (ACBUS4)
SPARE1: R99.2, U9.E3 (IO21_2), U10.32 (ACBUS5)
SPARE2: R100.2, U9.E1 (IO21_3), U10.33 (ACBUS6)
SPARE3: R101.2, U9.D1 (IO21_4), U10.34 (ACBUS7)
SUSPEED: U9.G1 (IO12_1), U10.36 (SUSPEED)
T_DIS: Q3.1 (D), R92.1, R102.2

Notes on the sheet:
Dual Channel Power Supply (LDO)
Transceivers
Microchip
need to decouple +5V more and address stability of ECU supply
???? What about this extra pin? and where is VCC_SRAM, and VNMA?
move TVS to after resistor to limit current
THESE ARE PLACEHOLDER RESISTERS THAT WE WILL SWITCH WITH THE TVS's IN THE LATER STAGES!!!!!
Input Stages
swapped all of the resisters in the input stages. they were the wrong values
the data sheet seems to tell me that these bufferes are within the minimum Vcc supply voltage range of 3-30volts
16 KHz filter
Debug Header
Autosport Connector
XDS100V2 CPLD
XDS100V2 FT2322HL
JTAG Interface
USB-
USB+
check that DM and DP are USB- and + (in datasheet)
connections: 5V_IN GND 2 AV 2 DI CAN1H CAN1L 5V
to mounting holes

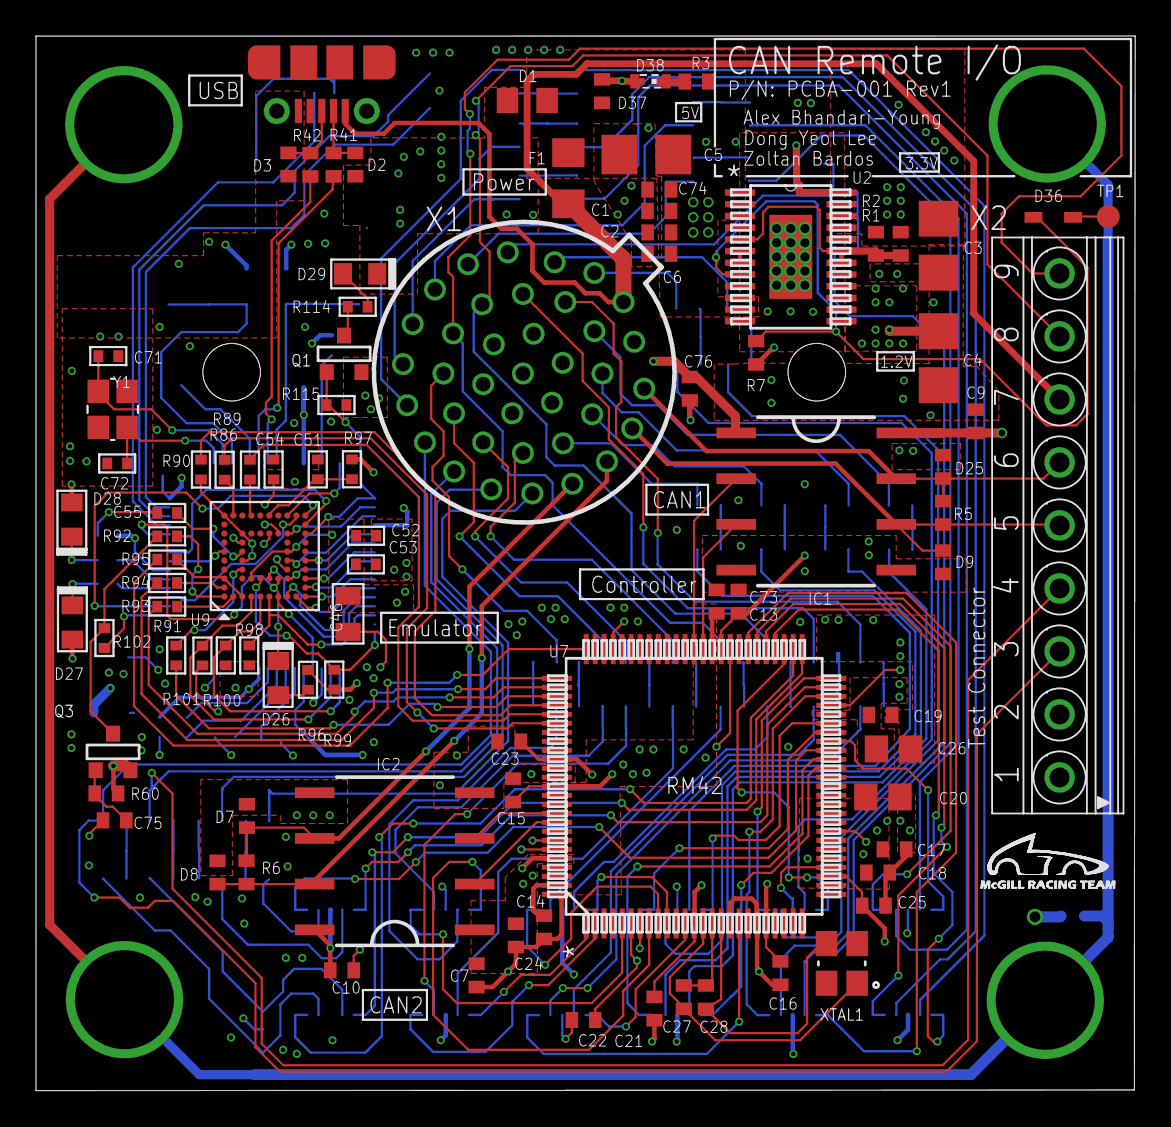
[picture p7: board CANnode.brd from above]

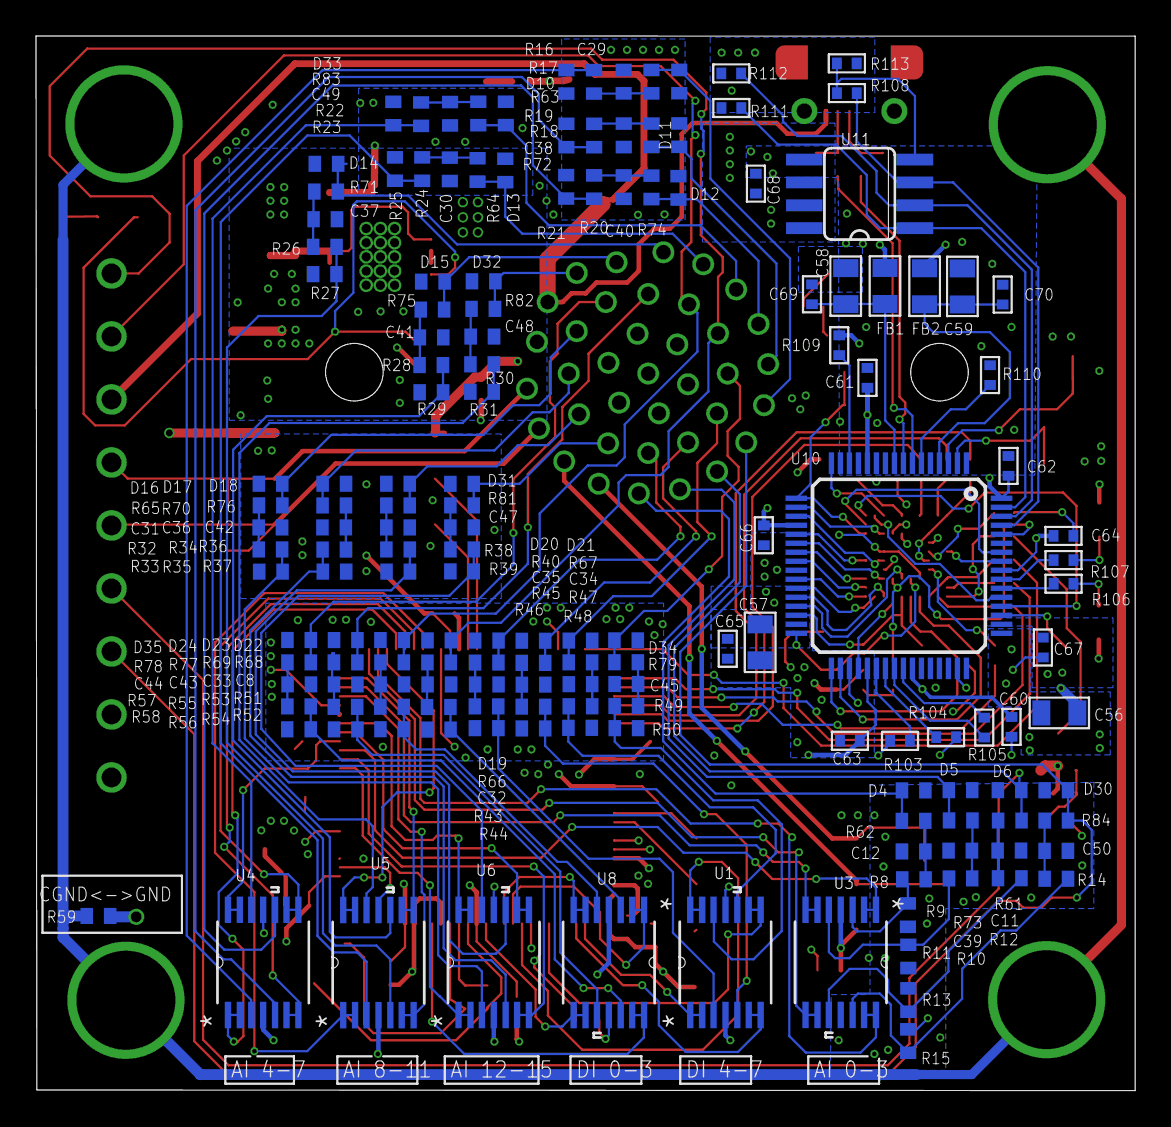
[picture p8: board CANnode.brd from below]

Board: 4 copper layers, 61.1 x 58.6 mm, 248 parts (157 on the bottom side), 184 nets.

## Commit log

2015-10-03 Added eagle schematics - power supply circuit started
    [CANnode.sch]
2015-11-20 Zoltan's compiling CAN example project
    builds and flashes, have not tested that CAN is working
    [can.obj, dabort.obj, esm.obj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]
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2015-11-23 sciSend working with CAN but some anomalies
    Transmits and receives on first try with full circuit wired on
    breadboard. After removing CAN2 it stalls waiting for transmit
    confirmation for the first byte.
    [can.obj, esm.obj, notification.obj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]
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2015-11-25 Added resistor dividers + buffers for analog inputs
    [CANnode.sch]
2016-01-14 Changes in input stage: copy and paste 3 times
    [CANnode.sch]
2016-01-14 Aligned to make the circuit look better
    [CANnode.sch]
2016-01-14 Changed TMS chip to RM42
    [CANnode.sch]
2016-01-16 added capacitor banks, moved the trancievers to look nicer
    [CANnode.sch]
2016-01-16 Rearranged pins for RM42
    [CANnode.sch]
2016-01-16 added real capacitors by hand, grouded VSS pins, started witinf VCC pins
    [CANnode.sch]
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2016-01-16 Wired power and CAN up
    [CANnode.sch]
2016-01-18 Added micro-usb part (not complete)
    [CANnode.sch]
2016-01-20 Wired analog and digital inputs to RM42
    [CANnode.sch]
2016-01-21 zoltan working on CAN, added tranciever
    [CANnode.sch]
2016-01-22 changed all the resisters in the input stage, removed a reduddant section, added headers, removed CAN caps, fixed grounds
    [CANnode.sch]
2016-01-22 Added TVS diodes to input stages. Cleaned up schematic. Added JTAG circuitry.
    [CANnode.sch]
2016-01-22 Changed 22R to 22, component names and rearranged wires
    [CANnode.sch]
2016-01-24 Added include path. Cleaned project.
    [can.obj, dabort.obj, esm.obj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]
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2016-01-26 started layout experiment. its difficult and weird first attempt.
    [CANnode.brd, CANnode.sch]
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2016-01-29 Placed digital input components on the board
    [CANnode.brd]
2016-01-30 Started placing analog input components
    [CANnode.brd]
2016-01-31 Placed analog input components on the board
    [CANnode.brd]
2016-02-03 Moved input components to bottom layer and wired
    [CANnode.brd]
2016-02-03 more layout and new files and such
    [CANnode.brd]
2016-02-04 moved buffers to the bottom layers and put more components on the board
    [CANnode.brd]
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2016-02-04 Deleted extra traces on the bottom layer that appear to be artifacts of the import.
    [CANnode.PcbDoc]
2016-02-05 Finished putting all the components on the board (but still needs to be more organized)
    [CANnode.brd, CANnode.sch]
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2016-02-10 played with vias and routing
    [CANnode.brd, CANnode.sch, DRILEGEND.CFG]
2016-02-11 Added another layer (Power)
    [CANnode.brd, CANnode.sch]
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2016-02-17 Fished wiring+3V3 and started wiring can components
    [CANnode.brd, CANnode.sch]
2016-02-17 Modifications on routing powers
    [CANnode.brd]
2016-02-17 Moved a LOT OF STUFF: SQUISH
    [CANnode.brd]
2016-02-18 Reduced the board even more (changes on top layer)
    [CANnode.brd]
2016-02-18 Focused on power positioning and some routing. Finished 5V_IN from connector and +5V to power supply. Placed caps for 3V3 and 1V2 around RM42. Placed and routed crystal.
    [CANnode.brd, CANnode.sch]
2016-02-18 Reduced the board size to 2.7inch*2.4inch (not done)
    [CANnode.brd]
2016-02-19 Reduced the size to 2.33inch*2.39inch
    [CANnode.brd]
2016-02-20 Reduced the size to 2.33 x 2.27
    [CANnode.brd]
2016-02-21 Routed CAN and RM42
    [CANnode.brd]
2016-02-23 Board size fixed. Bottom layer changed.
    [CANnode.brd]
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2016-02-25 Routing two JTAG chips (complicated and lots of vias)
    [CANnode.brd]
2016-02-25 Added missing JTAG connection to MCU
    [CANnode.brd, CANnode.sch]
2016-02-25 added comment to move TVS after resistor on USB input
    [CANnode.sch]
2016-02-26 Routed JTAG. Board size is reduced to 2.26x2.27.
    The fuse is put outside of the board for the future replacement.
    [CANnode.brd]
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2016-02-28 Connected JTAG to RM42. Board size reduced to 2.17x2.28. Relocated power supply components
    [CANnode.brd, CANnode.sch]
2016-02-28 Started locating input stages
    [CANnode.brd]
2016-02-29 A lot of work on input stages (not finished yet)
    [CANnode.brd]
2016-03-01 More work on input stages
    [CANnode.brd]
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2016-03-03 Finished routing input stages
    [CANnode.brd]
2016-03-03 Started drawing power planes
    [CANnode.brd]
2016-03-04 Continued working on power planes
    [CANnode.brd]
2016-03-05 Routed +5V, +1V8, +1V2
    [CANnode.brd]
2016-03-05 Started grounding input stages
    [CANnode.brd]
2016-03-06 Finished grounding bottom layer. Started routing +3V3
    [CANnode.brd]
2016-03-06 Finished routing bottom layer
    [CANnode.brd]
2016-03-07 Finished grounding and powering. Whole board needs to be reviewed
    [CANnode.brd]
2016-03-08 Routed missing JTAG to MCU connections
    [CANnode.brd]
2016-03-08 Changed mounting holes to big vias. Move the origin of the board.
    [CANnode.brd, CANnode.sch]
2016-03-09 Added CAM job and preliminary gerbers
    [CANnode.GBL, CANnode.GBO, CANnode.GBS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]
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2016-03-09 Started routing Debug headers
    [CANnode.brd, CANnode.sch]
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2016-03-10 Updated silkscreen, some ground pours, added pullup on jtag select line.
    [CANnode.brd, CANnode.sch]
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2016-03-10 Modified 5V pour for CAN
    [CANnode.brd]
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2016-03-10 Worked on DRC errors. Solved Polygon errors and overlapping erors. Reduced via sizes for some connections.
    [CANnode.brd]
2016-03-11 Post Bei review. USB runs closer together. CAN and JTAG need to be rerouted a bit.
    [CANnode.brd]
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2016-03-11 BOM finished except for res and cap part numbers. Need to check DNPs, 0 ohms, and crystals.
    [BOM_Final.xlsx]
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2016-03-11 Moved board origin to bottom left corner of board. Moved mounting holes inward for better mechanical strength.
    [CANnode.brd]
2016-03-11 Fixed an acute angle and increased size of ground trace on RM42
    [CANnode.brd]
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2016-03-11 Final review. Solved overlapping drc errors
    [CANnode.brd]
2016-03-11 changed power caps to 0805. working on BOM
    [BOM_Final.xlsx, CANnode.brd, CANnode.sch]
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2016-03-17 Revert "Submittable BOM"
    This reverts commit d765dbeff16fbf7401db7d2f9c843ce674e1691c.
    [BOM_Final.xlsx, BOM_Submit.xlsx]
2016-03-17 Revert "Revert "Submittable BOM""
    This reverts commit ef0a1a6dea697aed33fd8ed38d90974a342e9a82.
    [BOM_Final.xlsx, BOM_Submit.xlsx]
2016-03-17 Revert back to Submittable BOM
    [BOM_Final.xlsx, BOM_Submit.xlsx, CANnode.brd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]
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

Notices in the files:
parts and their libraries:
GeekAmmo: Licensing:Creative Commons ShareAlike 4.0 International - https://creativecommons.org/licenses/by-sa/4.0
